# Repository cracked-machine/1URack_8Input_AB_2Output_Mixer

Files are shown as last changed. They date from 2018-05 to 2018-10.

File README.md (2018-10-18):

# 1URack_8Input_AB_2Output_Mixer
Eurorack-compatible 1U 8-channel mixer with selectable A/B outputs. 

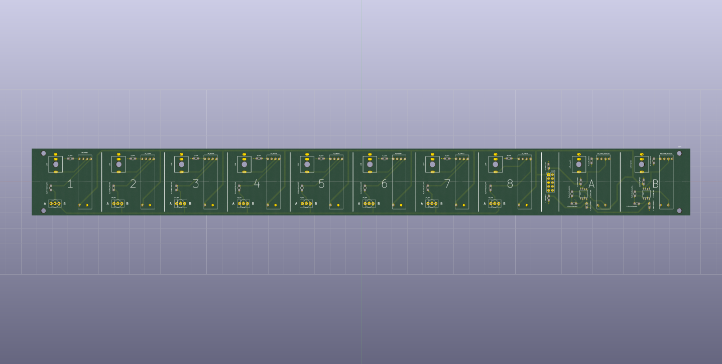
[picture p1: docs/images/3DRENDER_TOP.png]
3D Image


<a href="https://www.instagram.com/p/BnoBRM4nUFm/?utm_source=ig_web_copy_link">Link to demo video!</a>

Assembly Instructions:
======================

A. Resistors

1) 8 x 2K2 on all R_LEDX positions (**R_LED1** - **R_LED8**)
2) 8 x 10K on all R_ChannelAB_OAin_RinX positions (**R_ChannelAB_OAin_Rin1** - **R_ChannelAB_OAin_Rin8**)
3) 2 x 10K on **R_ChanA_OAin_Rf1** and **R_ChanB_OAin_Rf1**
4) 2 x 22K on **R_ChanA_OAout_Rin1** and **R_ChanB_OAout_Rin1**
5) 2 x 1K  on **R_ChanA_OAout1** and **R_ChanB_OAout1** 

B. Capacitors

1) 2 x 100nF on **C_ChanA_POSBY1** and **C_ChanB_POSBY1**
2) 2 x 100nF on **C_ChanA_NEGBY1** and **C_ChanB_NEGBY1**
3) 1 x 100nF on **C_PW_BYNEG1**
4) 1 x 100nF on **C_PW_BYPOS1**

C. SOIC components

1) 2 x TL072 on **U_ChanA_OA1** and **U_ChanB_OA1**

D. ThroughHole Components

1) Solder one fader per section (1-8, A and B). Will only fit one way
2) Solder one Jack socket per section (1-8, A and B). Will only fit one way
3) solder one switch per input section (1-8). Orientation does not matter.
4) Solder pin headers in the power supply holes (2x5).

Troubleshooting:
================

1. Signal check:

Run a VCO signal into each of the inputs and check the signal at both outputs. You can use either an amplifier or an scope at the outputs. It can be helpful to draw a 2x8 grid for the inputs/outputs so you can mark each one in turn as you check.

If any of the inputs fail to produce a signal at an output then check that input section. If no signal appears at one of the output then check that output section. See below for further checks....

2. Visual Inspection:

Most problems will arise from bad solder joints on the SMT components so be sure to make a final visual inspection when done. 
You might find it easier to do this after cleaning the flux off the pcb first. If in doubt retouch the solder joint.

3. Electrical check:

Check for +/-12V voltages at the power supply pins. Also check pins 8 (positive) and 4 (negative) on the two SOIC TL072 OpAmps. 

Use a DMM to check the continuity between component pins.  

Check the resistance on pins connected to each resistor after soldering. If you get an open circuit reading then resolder the component.  Seeing a resistance value significantly less than marked, can be a sign that another component has bad solder joints.

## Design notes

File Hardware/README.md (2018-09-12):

# 1URack_8Input_AB_2Output_Mixer
Eurorack-compatible 1U 8-channel mixer with selectable A/B outputs. 

3D Image

<a href="https://www.instagram.com/p/BnoBRM4nUFm/?utm_source=ig_web_copy_link">Link to demo video!</a>

Assembly Instructions:
======================

A. Resistors

1) 8 x 2K2 on all R_LEDX positions (R_LED1 - R_LED8)
2) 8 x 10K on all R_ChannelAB_OAin_RinX positions (R_ChannelAB_OAin_Rin1 - R_ChannelAB_OAin_Rin8)
3) 2 x 10K on R_ChanA_OAin_RfX (R_ChanA_OAin_Rf1 and R_ChanA_OAin_Rf2)
4) 2 x 22K on R_ChanB_OAout_RinX (R_ChanB_OAout_Rin1 and R_ChanB_OAout_Rin2)
5) 2 x 1K  on R_ChanB_OAoutX (R_ChanB_OAout1 and R_ChanB_OAout2) 

B. Capacitors

1) 2 x 100nF on C_ChanA_POSBYX (C_ChanA_POSBY1 and C_ChanA_POSBY2)
2) 2 x 100nF on C_ChanA_NEGBYX (C_ChanA_NEGBY1 and C_ChanA_NEGBY2)
3) 1 x 100nF on C_PW_BYNEG1
4) 1 x 100nF on C_PW_BYPOS1

C. SOIC components

1) 2 x TL072 on U_ChanA_OA1 and U_ChanB_OA1

D. ThroughHole Components

1) Solder one fader per section (1-8, A and B). Will only fit one way
2) Solder one Jack socket per section (1-8, A and B)
3) solder one switch per input section (1-8). Orientation does not matter.
4) Solder pin headers in the power supply holes (2x5).

Troubleshooting:
================

Visual Inspection:
Most problems will arise from bad solder joints on the SMT components so be sure to make a final visual inspection when done. 
You might find it easier to do this after cleaning the flux off the pcb first.

Measure Voltages:
Check for +/-12V voltages at the power supply pins. Also check pins 8 (positive) and 4 (negative) on the two SOIC TL072 OpAmps. 

For each input channel:
You wil be able to see the input signal if you probe the middle pin of the switch whilst in the off (center) position.
The resistance across resistor (R_ChannelAB_OAin_RinX) will be 2K5 (A position), 10K (Center position) and 8K (B position).

For the output channels:
On the SOIC TL072 OpAmps, probing pin 1 will show the input signals (NOT affected by output fader). Probing pin 6 will show the output signals (affected by output fader)

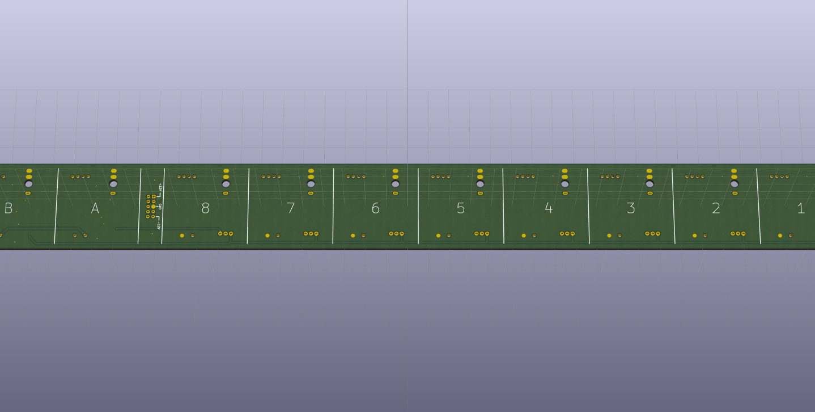
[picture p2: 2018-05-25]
docs/images/3DRENDER_BOTTOM.png

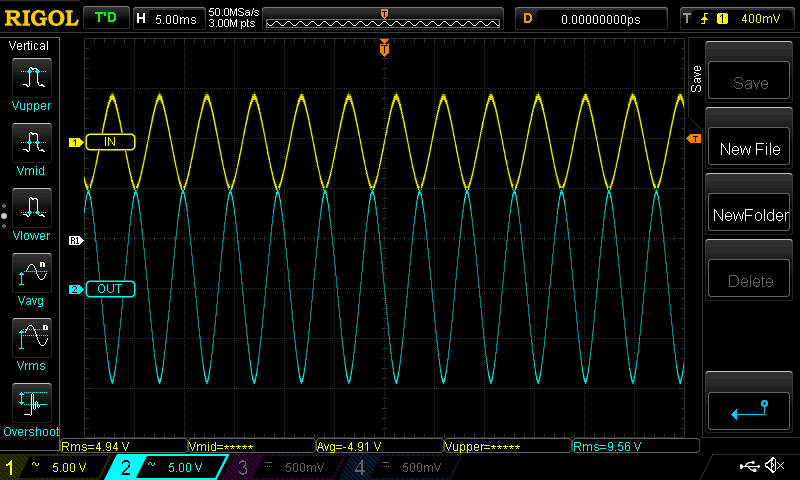
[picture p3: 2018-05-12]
docs/images/GainScope.png

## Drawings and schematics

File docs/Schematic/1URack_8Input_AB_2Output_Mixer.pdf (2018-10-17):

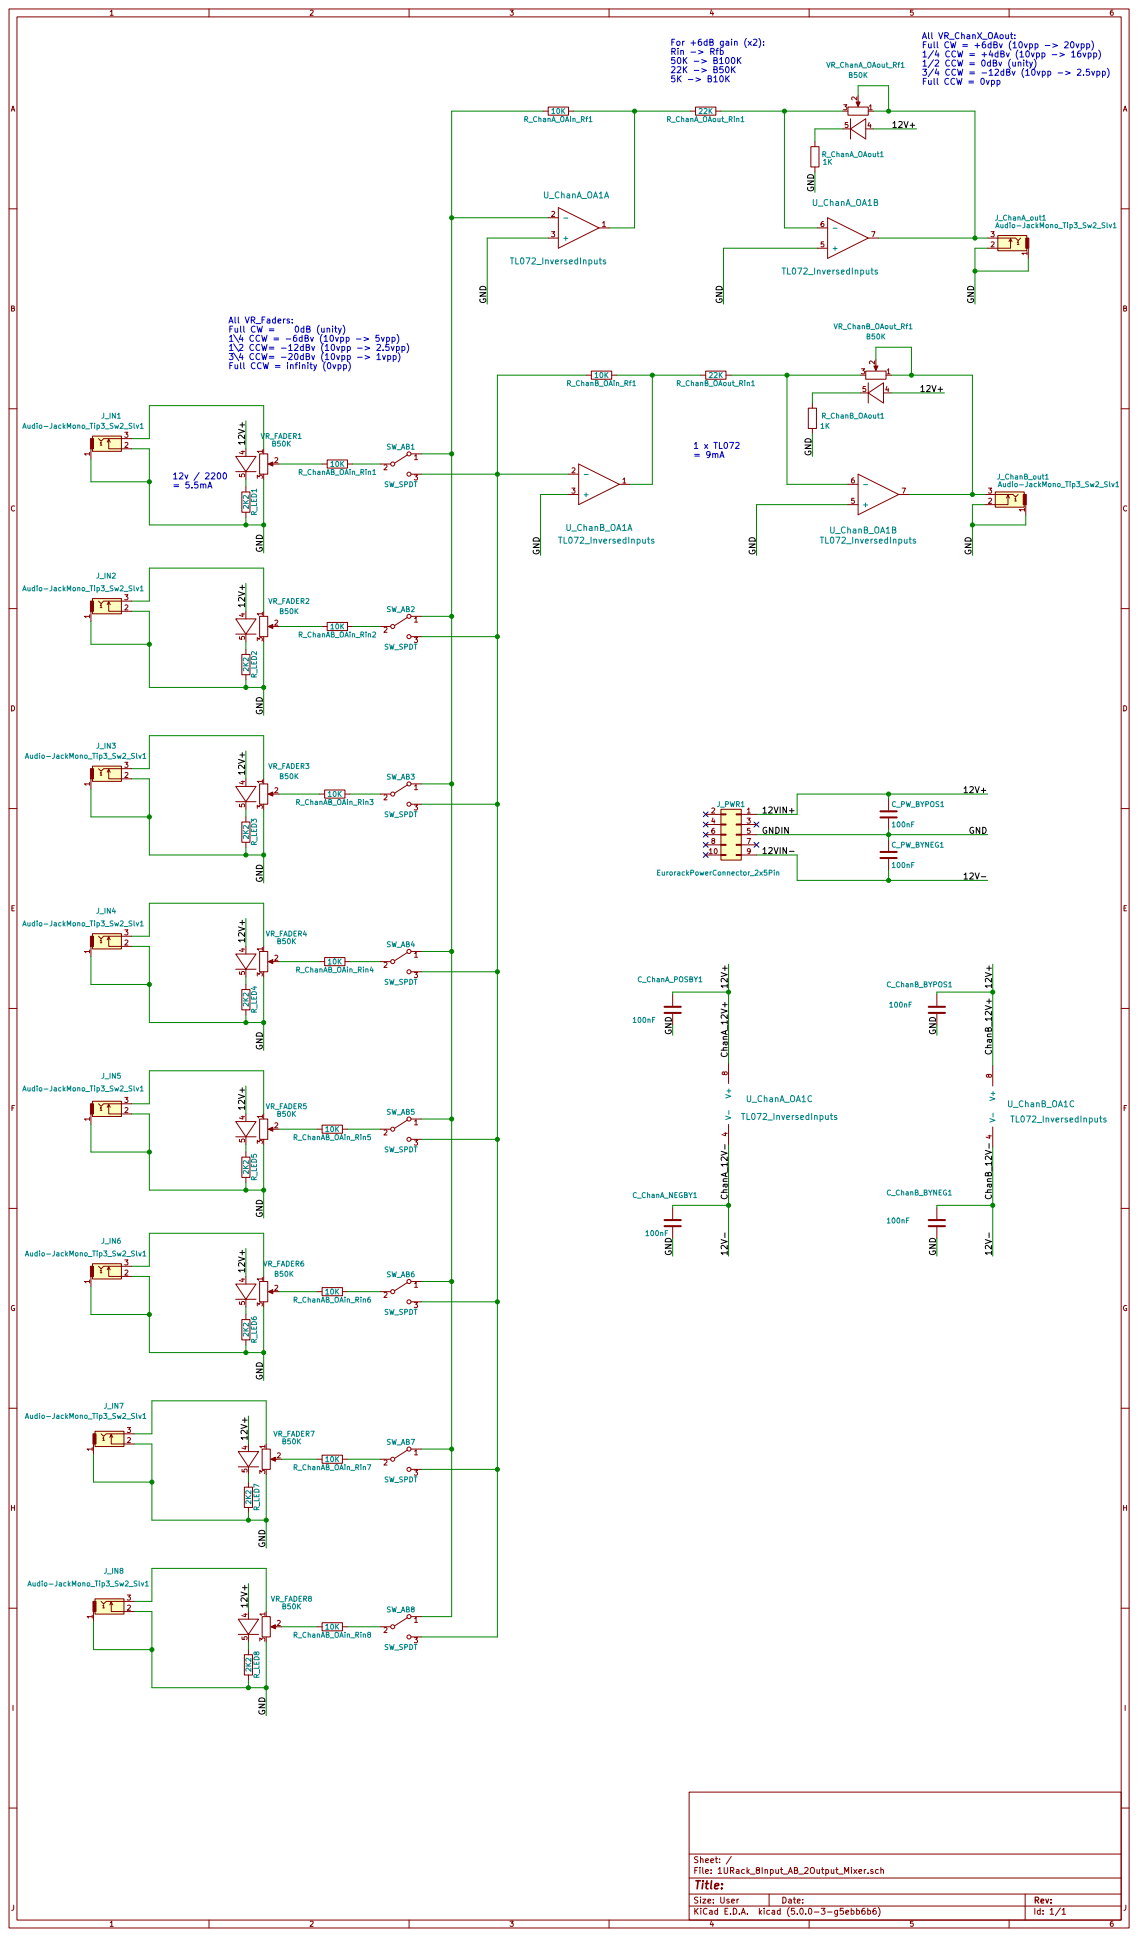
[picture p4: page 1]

File: 1URack_8Input_AB_2Output_Mixer.sch Sheet: / GND

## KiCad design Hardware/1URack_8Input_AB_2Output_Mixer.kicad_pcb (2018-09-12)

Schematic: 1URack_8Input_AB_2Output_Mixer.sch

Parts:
C_ChanA_NEGBY1: 100nF; C_0805_HandSoldering
C_ChanA_POSBY1: 100nF; C_0805_HandSoldering
C_ChanB_BYNEG1: 100nF; C_0805_HandSoldering
C_ChanB_BYPOS1: 100nF; C_0805_HandSoldering
C_PW_BYNEG1: 100nF; C_0805_HandSoldering
C_PW_BYPOS1: 100nF; C_0805_HandSoldering
J_ChanA_out1: Audio-JackMono_Tip3_Sw2_Slv1; Conn_3.5mmJackMono_Vertical_PJ301M-12
J_ChanB_out1: Audio-JackMono_Tip3_Sw2_Slv1; Conn_3.5mmJackMono_Vertical_PJ301M-12
J_IN1, J_IN2, J_IN3, J_IN4, J_IN5, J_IN6, J_IN7, J_IN8: Audio-JackMono_Tip3_Sw2_Slv1; Conn_3.5mmJackMono_Vertical_PJ301M-12
J_PWR1: EurorackPowerConnector_2x5Pin; Pin_Header_Straight_2x05_Pitch2.54mm
R_ChanAB_OAin_Rin1, R_ChanAB_OAin_Rin2, R_ChanAB_OAin_Rin3, R_ChanAB_OAin_Rin4, R_ChanAB_OAin_Rin5, R_ChanAB_OAin_Rin6, R_ChanAB_OAin_Rin7, R_ChanAB_OAin_Rin8: 10K; R_0805_HandSoldering
R_ChanA_OAin_Rf1: 10K; R_0805_HandSoldering
R_ChanA_OAout1: 1K; R_0805_HandSoldering
R_ChanA_OAout_Rin1: 22K; R_0805_HandSoldering
R_ChanB_OAin_Rf1: 10K; R_0805_HandSoldering
R_ChanB_OAout1: 1K; R_0805_HandSoldering
R_ChanB_OAout_Rin1: 22K; R_0805_HandSoldering
R_LED1, R_LED2, R_LED3, R_LED4, R_LED5, R_LED6, R_LED7, R_LED8: 2K2; R_0805_HandSoldering
SW_AB1, SW_AB2, SW_AB3, SW_AB4, SW_AB5, SW_AB6, SW_AB7, SW_AB8: SW_SPDT; Dailywell_SPDT
U_ChanA_OA1: TL072_InversedInputs; SOIC-8-N
U_ChanB_OA1: TL072_InversedInputs; SOIC-8-N
VR_ChanA_OAout_Rf1: B50K; Slider_PTL20_LED_35MM
VR_ChanB_OAout_Rf1: B50K; Slider_PTL20_LED_35MM
VR_FADER1, VR_FADER3, VR_FADER5, VR_FADER6, VR_FADER7, VR_FADER8: B50K; Slider_PTL20_LED_35MM
VR_FADER2, VR_FADER4: B5K; Slider_PTL20_LED_35MM

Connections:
/12V+: C_ChanA_POSBY1.1, C_ChanB_BYPOS1.1, C_PW_BYPOS1.1, J_PWR1.1, U_ChanA_OA1.8, U_ChanB_OA1.8, VR_ChanA_OAout_Rf1.4, VR_ChanB_OAout_Rf1.4, VR_FADER1.4, VR_FADER2.4, VR_FADER3.4, VR_FADER4.4, VR_FADER5.4, VR_FADER6.4, VR_FADER7.4, VR_FADER8.4
/12V-: C_ChanA_NEGBY1.1, C_ChanB_BYNEG1.1, C_PW_BYNEG1.2, J_PWR1.9, U_ChanA_OA1.4, U_ChanB_OA1.4
/GND: C_ChanA_NEGBY1.2, C_ChanA_POSBY1.2, C_ChanB_BYNEG1.2, C_ChanB_BYPOS1.2, C_PW_BYNEG1.1, C_PW_BYPOS1.2, J_ChanA_out1.1, J_ChanA_out1.2, J_ChanB_out1.1, J_ChanB_out1.2, J_IN1.1, J_IN1.2, J_IN2.1, J_IN2.2, J_IN3.1, J_IN3.2, J_IN4.1, J_IN4.2, J_IN5.1, J_IN5.2, J_IN6.1, J_IN6.2, J_IN7.1, J_IN7.2, J_IN8.1, J_IN8.2, J_PWR1.5, R_ChanA_OAout1.2, R_ChanB_OAout1.2, R_LED1.2, R_LED2.2, R_LED3.2, R_LED4.2, R_LED5.2, R_LED6.2, R_LED7.2, R_LED8.2, U_ChanA_OA1.3, U_ChanA_OA1.5, U_ChanB_OA1.3, U_ChanB_OA1.5, VR_FADER1.3, VR_FADER2.3, VR_FADER3.3, VR_FADER4.3, VR_FADER5.3, VR_FADER6.3, VR_FADER7.3, VR_FADER8.3
unnamed: J_ChanA_out1.3, U_ChanA_OA1.7, VR_ChanA_OAout_Rf1.1, VR_ChanA_OAout_Rf1.2
unnamed: J_ChanB_out1.3, U_ChanB_OA1.7, VR_ChanB_OAout_Rf1.1, VR_ChanB_OAout_Rf1.2
unnamed: J_IN1.3, VR_FADER1.1
unnamed: J_IN2.3, VR_FADER2.1
unnamed: J_IN3.3, VR_FADER3.1
unnamed: J_IN4.3, VR_FADER4.1
unnamed: J_IN5.3, VR_FADER5.1
unnamed: J_IN6.3, VR_FADER6.1
unnamed: J_IN7.3, VR_FADER7.1
unnamed: J_IN8.3, VR_FADER8.1
unnamed: R_ChanAB_OAin_Rin1.1, SW_AB1.2 (B)
unnamed: R_ChanAB_OAin_Rin1.2, VR_FADER1.2
unnamed: R_ChanAB_OAin_Rin2.1, SW_AB2.2 (B)
unnamed: R_ChanAB_OAin_Rin2.2, VR_FADER2.2
unnamed: R_ChanAB_OAin_Rin3.1, SW_AB3.2 (B)
unnamed: R_ChanAB_OAin_Rin3.2, VR_FADER3.2
unnamed: R_ChanAB_OAin_Rin4.1, SW_AB4.2 (B)
unnamed: R_ChanAB_OAin_Rin4.2, VR_FADER4.2
unnamed: R_ChanAB_OAin_Rin5.1, SW_AB5.2 (B)
unnamed: R_ChanAB_OAin_Rin5.2, VR_FADER5.2
unnamed: R_ChanAB_OAin_Rin6.1, SW_AB6.2 (B)
unnamed: R_ChanAB_OAin_Rin6.2, VR_FADER6.2
unnamed: R_ChanAB_OAin_Rin7.1, SW_AB7.2 (B)
unnamed: R_ChanAB_OAin_Rin7.2, VR_FADER7.2
unnamed: R_ChanAB_OAin_Rin8.1, SW_AB8.2 (B)
unnamed: R_ChanAB_OAin_Rin8.2, VR_FADER8.2
unnamed: R_ChanA_OAin_Rf1.1, R_ChanA_OAout_Rin1.2, U_ChanA_OA1.1
unnamed: R_ChanA_OAin_Rf1.2, SW_AB1.1 (A), SW_AB2.1 (A), SW_AB3.1 (A), SW_AB4.1 (A), SW_AB5.1 (A), SW_AB6.1 (A), SW_AB7.1 (A), SW_AB8.1 (A), U_ChanA_OA1.2
unnamed: R_ChanA_OAout1.1, VR_ChanA_OAout_Rf1.5
unnamed: R_ChanA_OAout_Rin1.1, U_ChanA_OA1.6, VR_ChanA_OAout_Rf1.3
unnamed: R_ChanB_OAin_Rf1.1, R_ChanB_OAout_Rin1.2, U_ChanB_OA1.1
unnamed: R_ChanB_OAin_Rf1.2, SW_AB1.3 (C), SW_AB2.3 (C), SW_AB3.3 (C), SW_AB4.3 (C), SW_AB5.3 (C), SW_AB6.3 (C), SW_AB7.3 (C), SW_AB8.3 (C), U_ChanB_OA1.2
unnamed: R_ChanB_OAout1.1, VR_ChanB_OAout_Rf1.5
unnamed: R_ChanB_OAout_Rin1.1, U_ChanB_OA1.6, VR_ChanB_OAout_Rf1.3
unnamed: R_LED1.1, VR_FADER1.5
unnamed: R_LED2.1, VR_FADER2.5
unnamed: R_LED3.1, VR_FADER3.5
unnamed: R_LED4.1, VR_FADER4.5
unnamed: R_LED5.1, VR_FADER5.5
unnamed: R_LED6.1, VR_FADER6.5
unnamed: R_LED7.1, VR_FADER7.5
unnamed: R_LED8.1, VR_FADER8.5

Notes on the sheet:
For +6dB gain (x2): Rin -> Rfb 50K -> B100K 22K -> B50K 5K -> B10K
All VR_ChanX_OAout: Full CW = +6dBv (10vpp -> 20vpp) 1/4 CCW = +4dBv (10vpp -> 16vpp) 1/2 CCW = 0dBv (unity) 3/4 CCW = -12dBv (10vpp -> 2.5vpp) Full CCW = 0vpp
All VR_Faders: Full CW = 0dB (unity) 1\4 CCW = -6dBv (10vpp -> 5vpp) 1\2 CCW= -12dBv (10vpp -> 2.5vpp) 3\4 CCW= -20dBv (10vpp -> 1vpp) Full CCW = infinity (0vpp)
12v / 2200 = 5.5mA
1 x TL072 = 9mA

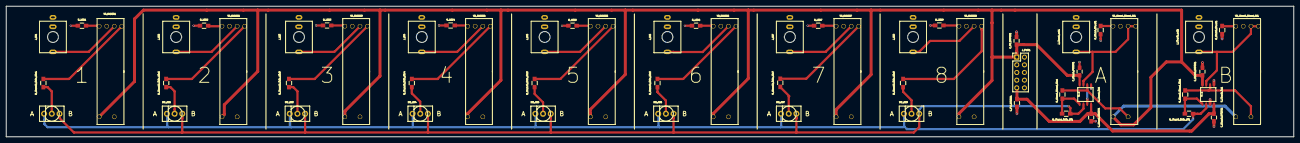
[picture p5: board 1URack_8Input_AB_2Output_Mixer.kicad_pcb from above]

Board: 2 copper layers, 426.0 x 43.2 mm, 59 parts (0 on the bottom side), 45 nets.

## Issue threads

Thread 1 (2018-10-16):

Wrong value for VR_FADER2 & VR_FADER4 in BOM

drsm79, 2018-10-16:
I think these are B50K like the others, but [the BOM](https://github.com/cracked-machine/1URack_8Input_AB_2Output_Mixer/blob/master/docs/1URack_8Input_AB_2Output_Mixer.csv) has them as B5K

cracked-machine, 2018-10-17:
oops. yes all the faders are 50k.

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

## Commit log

2018-05-12 update
    - Recalculated gain values on opamps
    [1URack_8Input_AB_2Output_Mixer.csv, 1URack_8Input_AB_2Output_Mixer.sch, 1URack_8Input_AB_2Output_Mixer_BOM.csv]
2018-05-21 First draft board layout
    [1URack_8Input_AB_2Output_Mixer.kicad_pcb, 1URack_8Input_AB_2Output_Mixer.sch]
2018-05-23 second draft
    [1URack_8Input_AB_2Output_Mixer.kicad_pcb, 1URack_8Input_AB_2Output_Mixer.sch, _saved_1URack_8Input_AB_2Output_Mixer.sch]
2018-05-24 third draft
    [1URack_8Input_AB_2Output_Mixer.csv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]
2018-05-24 minor updates
    [1URack_8Input_AB_2Output_Mixer-B.Cu.gbr, 1URack_8Input_AB_2Output_Mixer-B.Mask.gbr, 1URack_8Input_AB_2Output_Mixer-B.SilkS.gbr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]
2018-05-26 BOM update
    [1URack_8Input_AB_2Output_Mixer.csv]
2018-09-12 updated to Kicad 5
    [1URack_8Input_AB_2Output_Mixer-2018-09-12-07-44-46.sch, 1URack_8Input_AB_2Output_Mixer.kicad_pcb, 1URack_8Input_AB_2Output_Mixer.sch]
2018-10-02 Added front panel design
    [1URack_8Input_AB_2Output_Mixer-2018-09-12-07-44-46.sch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]
2018-10-10 Created Front Panel REVB
    [FrontPanel_1URack_8Input_AB_2Output_Mixer.kicad_pcb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]
2018-10-17 Documentation corrections and restructure
    [1URack_8Input_AB_2Output_Mixer-B.Cu.gbr, 1URack_8Input_AB_2Output_Mixer-B.Mask.gbr, 1URack_8Input_AB_2Output_Mixer-B.SilkS.gbr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]
